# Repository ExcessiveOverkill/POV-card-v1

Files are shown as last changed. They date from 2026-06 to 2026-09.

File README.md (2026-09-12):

# Persistence of Vision Badge
Turn on then shake side to side to view the images or animations programmed into the badge.

## Specs:
- Requires 2x CR2032 batteries (badge is not rechargeable)
- Credit card sized: 2.1" x 3.3" (54mm x 84mm)
- 0.8mm PCB thickness, 4mm total thickness with components
- Black PCB soldermask
- 32 bright white leds
- ENIG (thin gold) plated

## Features:
- Image or animation display
- User programmable images/animations over USB-C
- User configurable modes set by tapping the badge
- 4-bit grayscale image support
- Many new display modes
- XYZ Accelerometer
- True power-off (batteries last when not in use)
- Auto power-off

# How to use:
## Turning On:
1. Press "ON" button on badge.
2. Badge will display power-on animation when first powered on.

Pressing the "ON" button once badge is already on will have no effect.

## Turning Off:
1. Do nothing
2. Badge will automatically power off after it is no longer being interacted with for around 20 seconds. It will also power off regardless of interaction after 5 minutes.

## Changing Mode:
1. Turn badge on
2. Tap top of badge downward 3 times quickly to enter the mode menue, it should display the current mode by turning on an LED. The distance the LED is from the bottom of the badge shows what mode it is in.
3. Tap top of badge downward to move LED down, Tap bottom of badge upward to move LED up
4. Wait 3 seconds for badge to enter new mode. You may shake the badge while in the mode menu to view what mode is selected.
5. Done!

## USB Programming:
1. Turn badge on
2. Plug into computer using a USB-C cable, ensure the cable can carry data and not only power.
3. Badge will display slow pulsing to indicate USB connection.
4. Badge should show up as a USB storage device (flash drive).
5. Copy your BMP file to the badge
6. Done!
   
### BMP File Requirements:
- 1-bit or 4-bit grayscale
- 8, 16, or 32 pixels tall
- 128 or less pixels wide (per frame)
- Filename must end in "1" or "2" to indicate which slot you want to program
- For animations (multiple frames displayed in sequence), the filename must start with "SEQ"
- Animation frames must be separated by a 1 pixel wide column of alternating colors (0-1 for 1-bit, 0-15 for 4-bit). With the top pixel starting as 1 or 15 (white).
- File size must be less than 2KB

## How to get a good image
Image quality greatly depends on the shaking motion. Use mode 8: "IMAGE LINE TEST" to visualize your shake motion.
### Things to improve display quality
- Hold badge further away
- Smooth, uniform shaking. Slower and more consistent is better than fast and crazy.
- Shake left/right, not tilted or up/down
- Symmetrical movement, *not* like trying to shake ketchup out of a bottle.

## Modes
### 1. DISPLAY BOTH
Display both the pre-programmed image/animation shipped with the badge as well as all custom user-programmed images/animations.

### 2. DISPLAY CUSTOM
Display only the custom user-programmed images/animations.

### 3. LEVEL
Emulates a bubble level. Hold the badge edge against a vertical or horizontal surface. Use the "LEVEL CAL" mode to improve accuracy.

### 4. BALL SIM
LEDs display a "ball" that reacts to how you move and tilt the badge.

### 5. SAVE MODE
Save the last selected mode and automatically switch to it on the next power-on.
This function requires verification (see below).

### 6. LEVEL CAL
Calibrate the angles the badge uses for "LEVEL" mode. After entering this mode, hold the long badge still against a known horizontal surface until the LEDs all turn on. Then hold the short edge still against the surface until the "bubble" resets to center.
This function requires verification (see below).

### 7. RESET
Clears all user-programmed memory. Badge will power off after this mode is selected.
This function requires verification (see below).

### 8. IMAGE LINE TEST
Displays a diagonal line. Useful for practicing the correct shake technique to get the best display results.
The line should be perfectly straight and vertical when you shake the badge. Slight distortion is acceptable, but if it is very distorted, read the "How to get a good image" section.

## Firmware Update (DANGER)
### 9. USB Device Firmware Update
Allows the badge to be fully reprogrammed with a new binary file using STM32CubeProgrammer over the USB port. `-ob nBOOT0=1` must be added when using the programmer to reset the DFU bit, otherwise the badge will be stuck in DFU mode. Once this mode is entered, the badge will not function until reprogrammed! "ON" button must be held down to program the badge in this mode *or* with an ST-LINK.
User-memory will also be cleared.

## Mode Verification
Certain modes are protected by a verification step to prevent accidental triggering.
These modes will display a bar at the bottom the image that slowly shrinks while you shake the badge.
You must continuously shake the badge until the bar is gone to enable the selected mode.

# Warnings/Notices:
- The badge is a bare PCB, it is very susceptible water and metallic objects and dust. Keep clean and do not put in contact with loose conductive objects
- Badge is not rechargeable, the USB-C port does not supply power to the badge circuitry.
- This "Development Edition" is the first publicly available version. There may be unforeseen issues with hardware or software that affect functionality. However we will do our best to verify all use cases and resolve potential issues before you receive your badge.
- Persistence-of-vision effects are notoriously hard to film. Cameras will not capture the effect well without a very slow shutter speed.
- Attached lanyards or clips that rattle against the badge will affect the accelerometer reading and can make the image distorted.

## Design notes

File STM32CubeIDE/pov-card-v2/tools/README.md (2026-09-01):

# POV-card-v2 asset tools

Offline code generators that bake image/font data into the firmware. They are **not**
part of the build — run them by hand when the assets change, then rebuild in STM32CubeIDE.

## Prerequisites

```
pip install pillow
```

## bmp_convert.py — built-in POV images

Converts up to **2** BMP files into `../Core/Inc/eo_image_data.h`
(`const uint8_t eo_image_data[]` + `const Image_Metadata eo_metadata[2]`), which `main.c`
pulls in with `#include "eo_image_data.h"` and places in the `.eo_image_data` flash region.

1. Put the BMP next to this script (or give a path relative to it).
2. Edit `INPUT_FILES` at the top of `bmp_convert.py` (1 or 2 entries).
3. `python bmp_convert.py`
4. Rebuild the `Debug` configuration in STM32CubeIDE and flash.

BMP constraints (enforced by the script):

| Property | Allowed |
|---|---|
| Bit depth | 1-bit **or** 4-bit, uncompressed |
| Height | 8, 16, or 32 px |
| Width | any (≤ 128 recommended); columns become POV lines |
| Frames | filename contains `sequence` → auto-split on alternating separator columns; else 1 frame; ≤ 128 |

Per-image timing is set by the `*_DISPLAY_CYCLES` / `*_CYCLE_COUNT` constants at the top
of the script (`SINGLE_*` for normal images, `SEQUENCE_*` for `sequence` animations).

`eo_metadata` is always exactly 2 entries; a missing second image is emitted as a zeroed
(`mode = ONE_BIT`, `frame_count = 0`) placeholder.

## letter_convert.py — A–Z label font

Converts `7x5_letters.png` (a 7-px-tall A–Z strip) into `font_data.txt`, a
`const uint8_t letter_pixels[]` table. That array is currently **pasted by hand** into
`../Core/Src/main.c` (search for `letter_pixels[]`). Bit layout: bits 6–0 = column pixels
(bit 0 = bottom row); bit 7 = last column of the glyph.

```
python letter_convert.py
```

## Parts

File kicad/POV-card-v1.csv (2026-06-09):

Reference | Value | Footprint | Qty | Manufacturer | LCSC# | Manufacturer part number
BT1,BT2 | Battery_Cell | footprints:cr2032 | 2 | MYOUNG | C19184123 | MY-2032-30-R
C1,C2,C3 | 4.7uf | Capacitor_SMD:C_0402_1005Metric | 3 | Samsung Electro-Mechanics | C23733 | CL05A475MP5NRNC
C4,C5,C6,C7,C8,C9,C10,C11 | .1uf | Capacitor_SMD:C_0402_1005Metric | 8 | Samsung Electro-Mechanics | C1525 | CL05B104KO5NNNC
D1,D2,D3,D4,D5,D6,D7,D8,D9,D10,D11,D12,D13,D14,D15,D16,D17,D18,D19,D20,D21,D22,D23,D24,D25,D26,D27,D28,D29,D30,D31,D32 | LED | LED_SMD:LED_0603_1608Metric | 32 | Hubei KENTO Elec | C2290 | KT-0603W
J2 | USB_C_Receptacle_USB2.0_16P | Connector_USB:USB_C_Receptacle_G-Switch_GT-USB-7010ASV | 1 | G-Switch | C2988369 | GT-USB-7010ASV
Q1 | Q_PMOS_GSD | Package_TO_SOT_SMD:SOT-23 | 1 | r Alpha & Omega Semicon | C15127 | AO3401A
Q2 | Q_NMOS_GSD | Package_TO_SOT_SMD:SOT-23 | 1 | Jiangsu Changjing Electronics Technology Co., Ltd. | C8545 | 2N7002
R1,R2,R4,R5 | 10k | Resistor_SMD:R_0402_1005Metric | 4 | UNI-ROYAL | C25744 | 0402WGF1002TCE
R3 | 1k | Resistor_SMD:R_0402_1005Metric | 1 | UNI-ROYAL | C11702 | 0402WGF1001TCE
SW1 | SW_Push | Button_Switch_SMD:SW_Push_1P1T_XKB_TS-1187A | 1 | XKB Connection | C318884 | TS-1187A-B-A-B
U1 | SC7A20 | Package_LGA:LGA-12_2x2mm_P0.5mm | 1 | Hangzhou Silan Microelectronics | C19274408 | SC7A20HTR
U2,U4 | USBLC6-2SC6 | Package_TO_SOT_SMD:SOT-23-6 | 2 | UMW(Youtai Semiconductor Co., Ltd.) | C2687116 | USBLC6-2SC6
U3,U5 | TLC59283RGER | footprints:RGE24_2P1X2P1_TEX | 2 | Texas Instruments | C485815 | TLC59283RGER
U6 | STM32C071G8Ux | Package_DFN_QFN:QFN-28_4x4mm_P0.5mm | 1 | STMicroelectronics | C44521811 | STM32C071G8U6
U7 | HT75xx-1-SOT89 | Package_TO_SOT_SMD:SOT-89-3 | 1 | Holtek Semicon | t # C14289 | HT7533-1

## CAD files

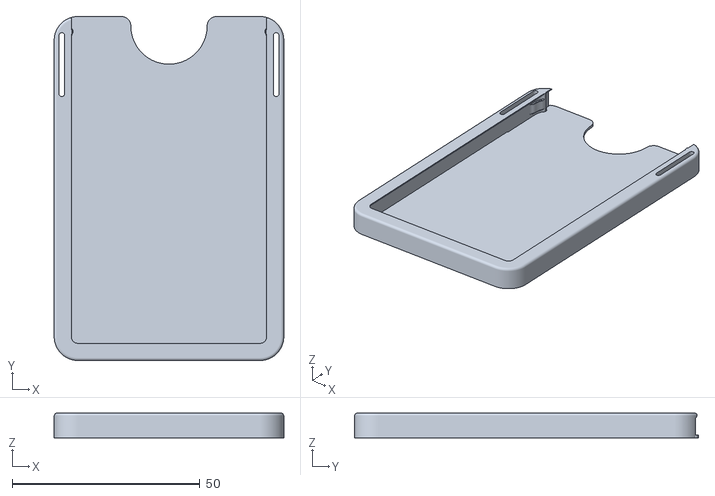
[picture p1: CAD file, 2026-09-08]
POV Badge Holder v3.stl
61.2 x 91.7 x 6.60

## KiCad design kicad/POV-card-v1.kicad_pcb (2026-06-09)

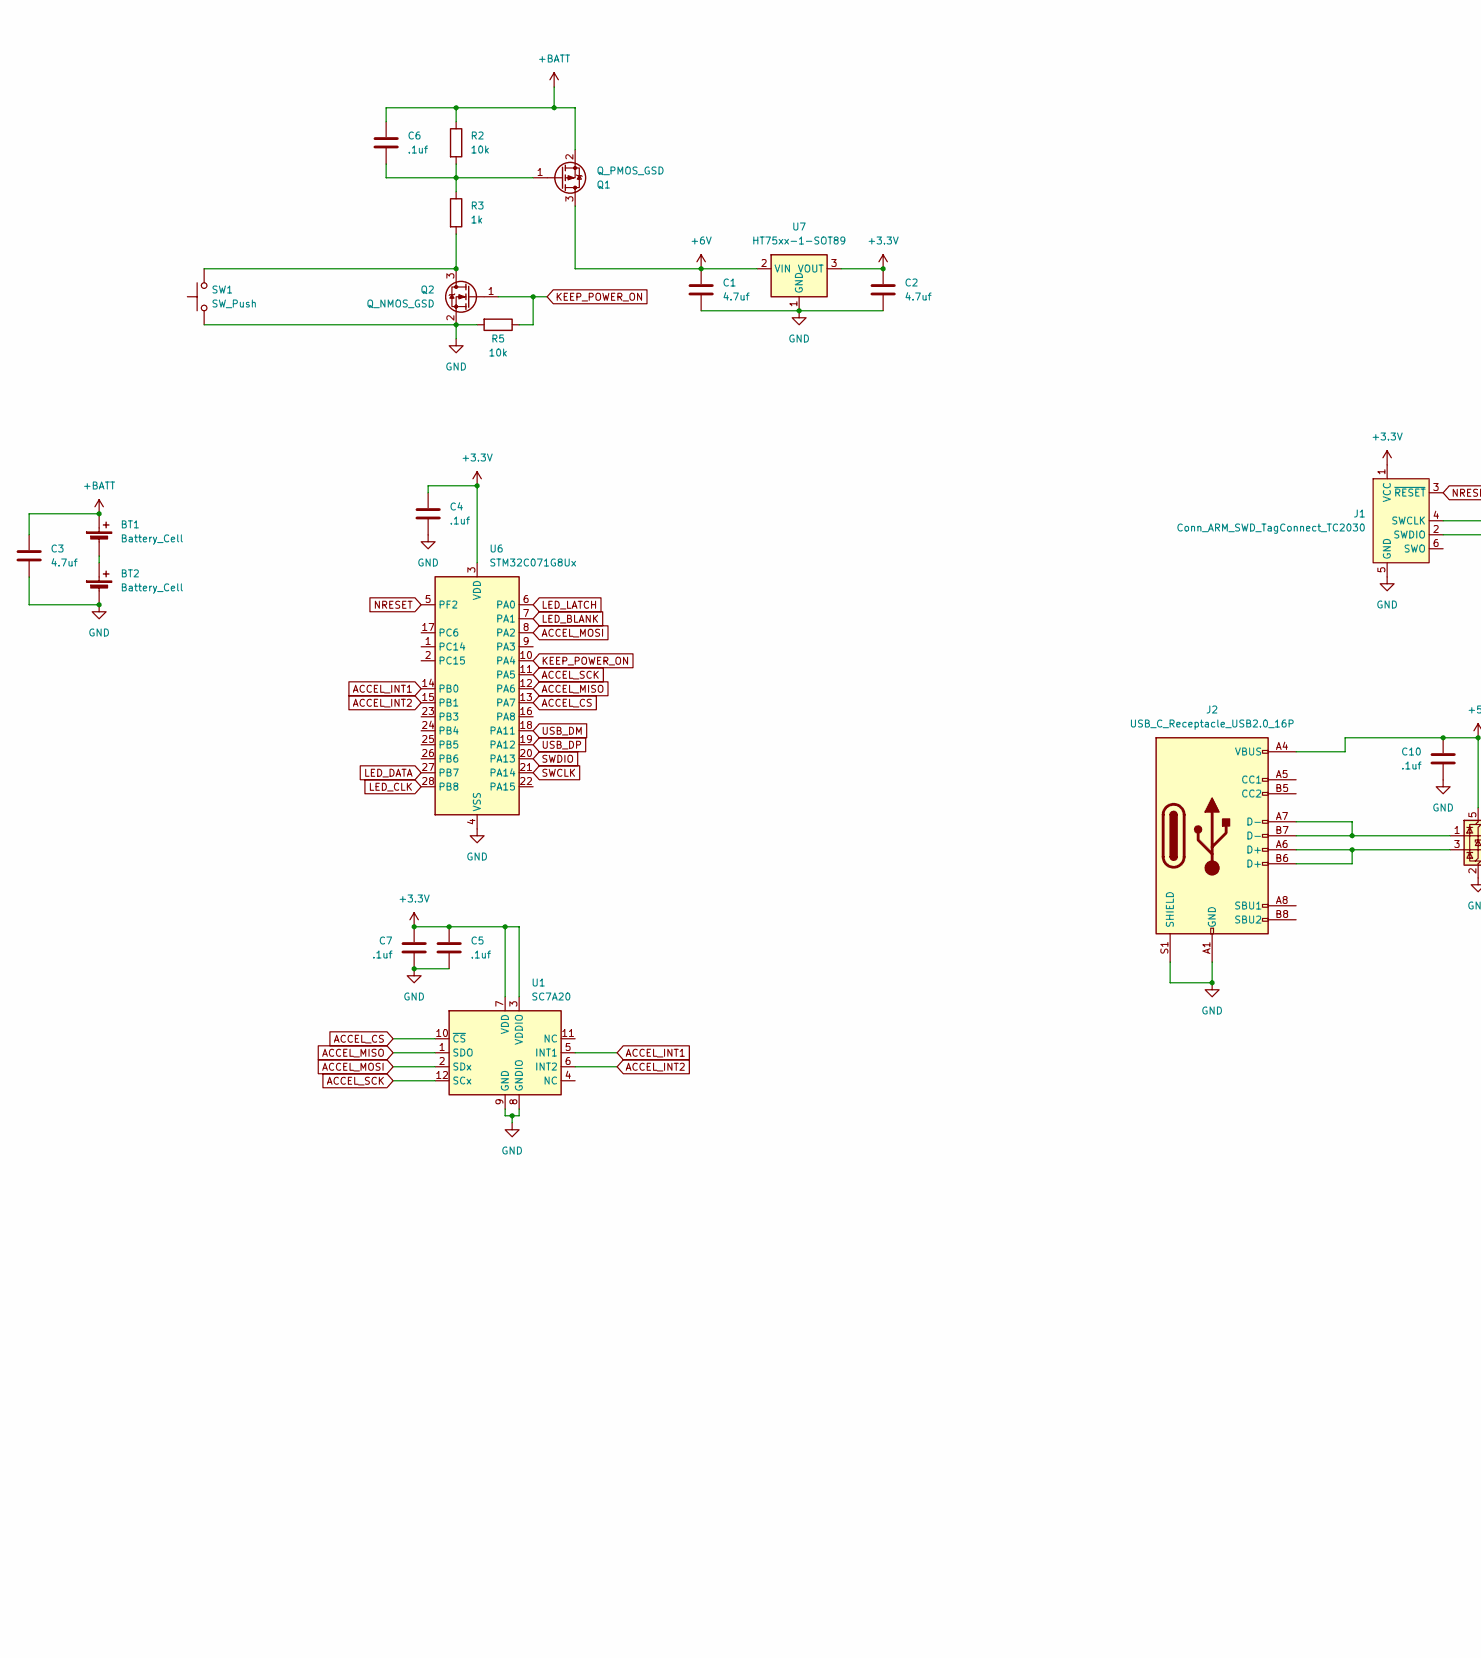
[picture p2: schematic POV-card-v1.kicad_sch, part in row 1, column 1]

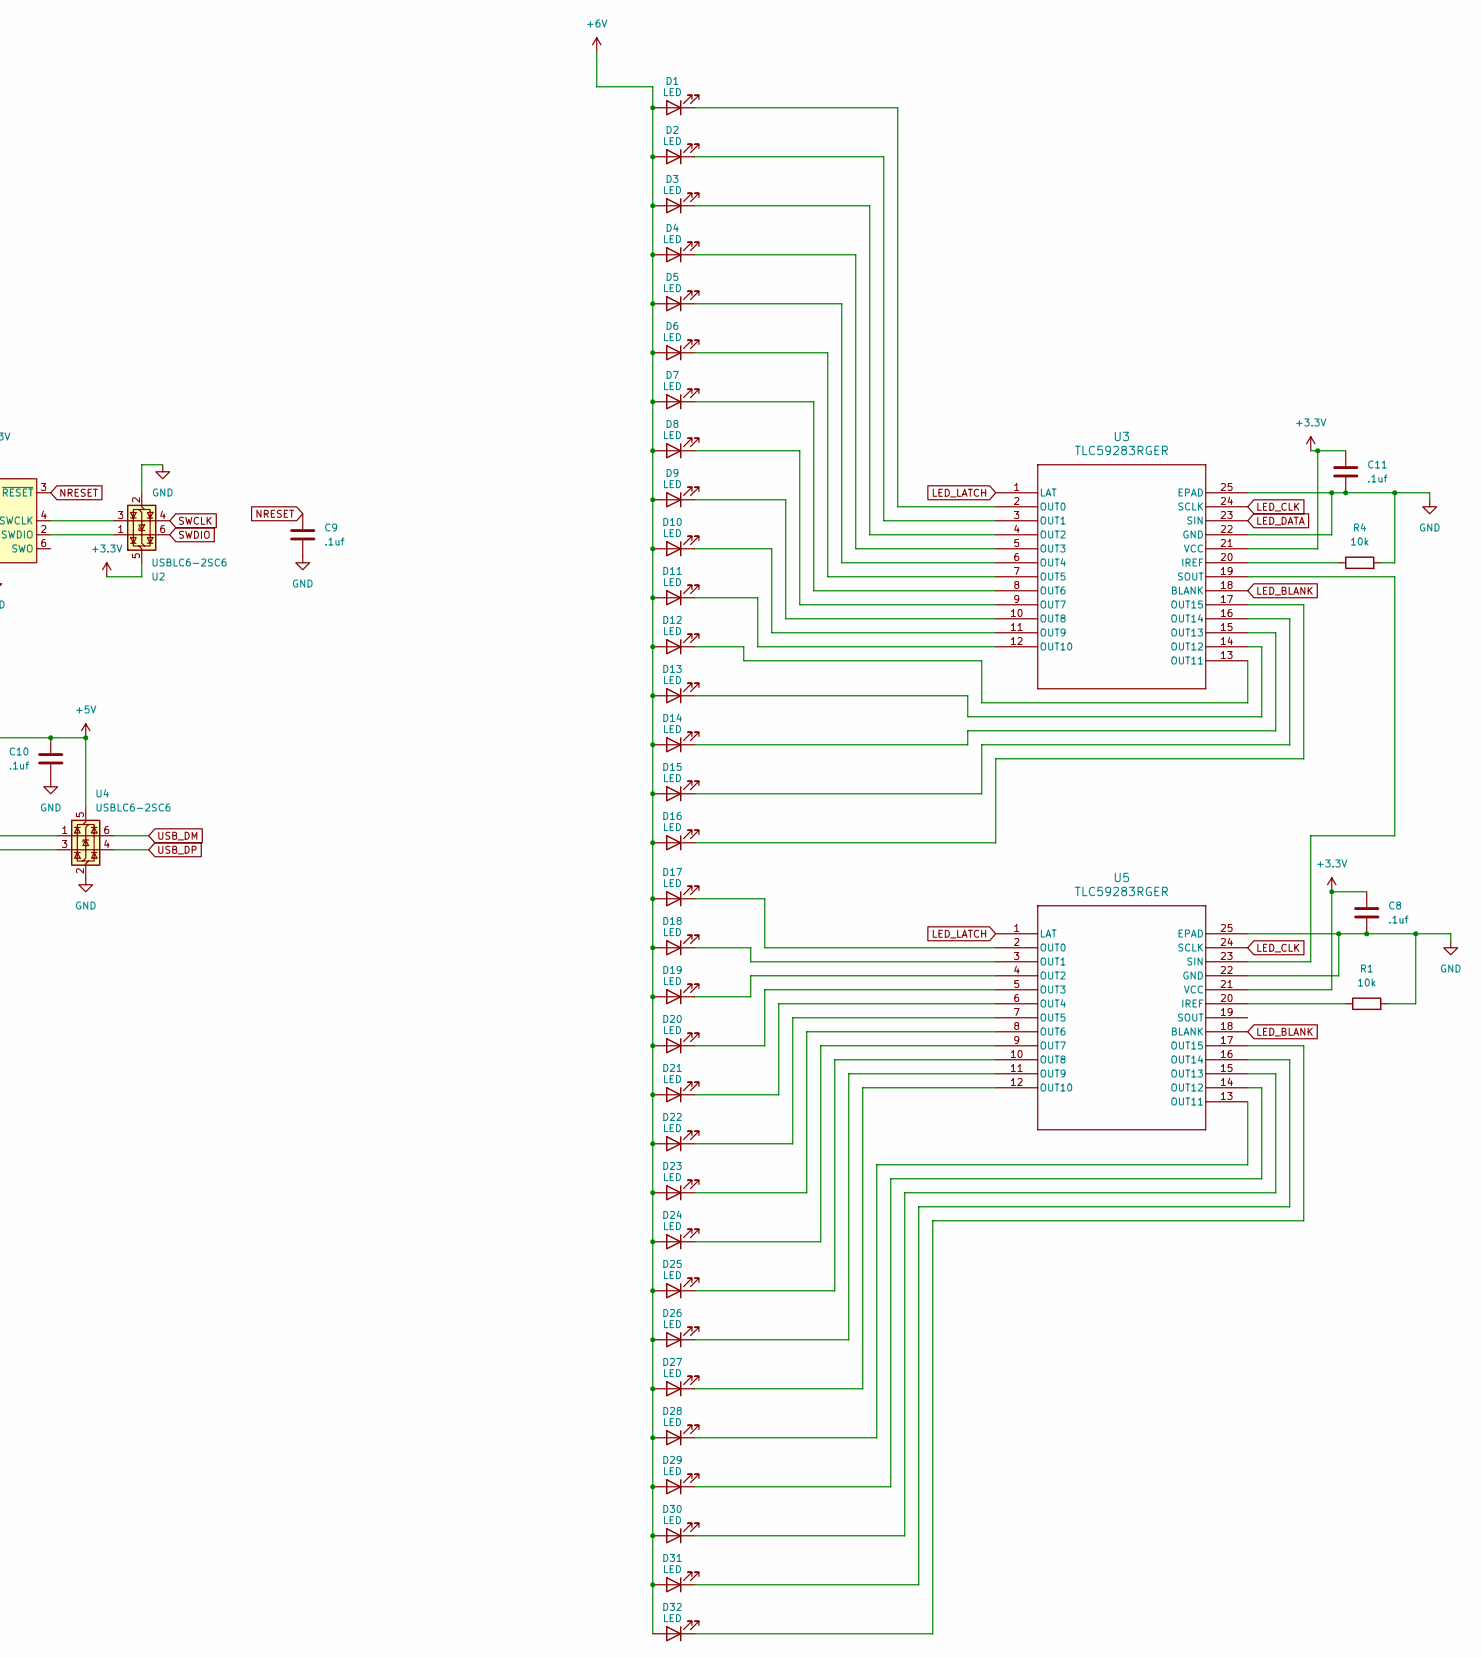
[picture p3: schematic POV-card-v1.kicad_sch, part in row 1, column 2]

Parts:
BT1, BT2: Battery_Cell; cr2032; Manufacturer part number MY-2032-30-R; LCSC# C19184123
C1, C2, C3: 4.7uf; C_0402_1005Metric; Manufacturer part number CL05A475MP5NRNC; LCSC# C23733
C4, C5, C6, C7, C8, C9, C10, C11: .1uf; C_0402_1005Metric; Manufacturer part number CL05B104KO5NNNC; LCSC# C1525
D1, D2, D3, D4, D5, D6, D7, D8, D9, D10, D11, D12, D13, D14, D15, D16, D17, D18, D19, D20, D21, D22, D23, D24, D25, D26, D27, D28, D29, D30, D31, D32: LED; LED_0603_1608Metric; Manufacturer part number KT-0603W; LCSC# C2290
J1: Conn_ARM_SWD_TagConnect_TC2030; Tag-Connect_TC2030-IDC-FP_2x03_P1.27mm_Vertical
J2: USB_C_Receptacle_USB2.0_16P; USB_C_Receptacle_G-Switch_GT-USB-7010ASV; Manufacturer part number GT-USB-7010ASV; LCSC# C2988369
Q1: Q_PMOS_GSD; SOT-23; Manufacturer part number AO3401A; LCSC# C15127
Q2: Q_NMOS_GSD; SOT-23; Manufacturer part number 2N7002; LCSC# C8545
R1, R2, R4, R5: 10k; R_0402_1005Metric; Manufacturer part number 0402WGF1002TCE; LCSC# C25744
R3: 1k; R_0402_1005Metric; Manufacturer part number 0402WGF1001TCE; LCSC# C11702
SW1: SW_Push; SW_Push_1P1T_XKB_TS-1187A; Manufacturer part number TS-1187A-B-A-B; LCSC# C318884
U1: SC7A20; LGA-12_2x2mm_P0.5mm; Manufacturer part number SC7A20HTR; LCSC# C19274408
U2, U4: USBLC6-2SC6; SOT-23-6; Manufacturer part number USBLC6-2SC6; LCSC# C2687116
U3, U5: TLC59283RGER; RGE24_2P1X2P1_TEX; Manufacturer part number TLC59283RGER; LCSC# C485815
U6: STM32C071G8Ux; QFN-28_4x4mm_P0.5mm; Manufacturer part number STM32C071G8U6; LCSC# C44521811
U7: HT75xx-1-SOT89; SOT-89-3; Manufacturer part number HT7533-1; LCSC# t # C14289

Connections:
+3.3V: C2.1, C4.1, C5.1, C7.1, C8.1, C11.1, J1.1 (VCC), U1.3 (VDDIO), U1.7 (VDD), U2.5 (VBUS), U3.21 (VCC), U5.21 (VCC), U6.3 (VDD), U7.3 (VOUT)
+5V: C10.1, J2.A4 (VBUS), J2.A9 (VBUS), J2.B4 (VBUS), J2.B9 (VBUS), U4.5 (VBUS)
+6V: C1.1, D1.2 (A), D2.2 (A), D3.2 (A), D4.2 (A), D5.2 (A), D6.2 (A), D7.2 (A), D8.2 (A), D9.2 (A), D10.2 (A), D11.2 (A), D12.2 (A), D13.2 (A), D14.2 (A), D15.2 (A), D16.2 (A), D17.2 (A), D18.2 (A), D19.2 (A), D20.2 (A), D21.2 (A), D22.2 (A), D23.2 (A), D24.2 (A), D25.2 (A), D26.2 (A), D27.2 (A), D28.2 (A), D29.2 (A), D30.2 (A), D31.2 (A), D32.2 (A), Q1.3 (D), U7.2 (VIN)
+BATT: BT1.1 (+), C3.1, C6.1, Q1.2 (S), R2.1
ACCEL_CS: U1.10 (~CS), U6.13 (PA7)
ACCEL_INT1: U1.5 (INT1), U6.14 (PB0)
ACCEL_INT2: U1.6 (INT2), U6.15 (PB1)
ACCEL_MISO: U1.1 (SDO), U6.12 (PA6)
ACCEL_MOSI: U1.2 (SDx), U6.8 (PA2)
ACCEL_SCK: U1.12 (SCx), U6.11 (PA5)
GND: BT2.2 (-), C1.2, C2.2, C3.2, C4.2, C5.2, C7.2, C8.2, C9.2, C10.2, C11.2, J1.5 (GND), J2.A1 (GND), J2.A12 (GND), J2.B1 (GND), J2.B12 (GND), J2.S1 (SHIELD), Q2.2 (S), R1.2, R4.2, R5.2, SW1.1, U1.8 (GNDIO), U1.9 (GND), U2.2 (GND), U3.22 (GND), U3.25 (EPAD), U4.2 (GND), U5.22 (GND), U5.25 (EPAD), U6.4 (VSS), U7.1 (GND)
KEEP_POWER_ON: Q2.1 (G), R5.1, U6.10 (PA4)
LED_BLANK: U3.18 (BLANK), U5.18 (BLANK), U6.7 (PA1)
LED_CLK: U3.24 (SCLK), U5.24 (SCLK), U6.28 (PB8)
LED_DATA: U3.23 (SIN), U6.27 (PB7)
LED_LATCH: U3.1 (LAT), U5.1 (LAT), U6.6 (PA0)
NRESET: C9.1, J1.3 (~RESET), U6.5 (PF2)
unnamed: BT1.2 (-), BT2.1 (+)
unnamed: D1.1 (K), U3.2 (OUT0)
unnamed: D2.1 (K), U3.3 (OUT1)
unnamed: D3.1 (K), U3.4 (OUT2)
unnamed: D4.1 (K), U3.5 (OUT3)
unnamed: D5.1 (K), U3.6 (OUT4)
unnamed: D6.1 (K), U3.7 (OUT5)
unnamed: D7.1 (K), U3.8 (OUT6)
unnamed: D8.1 (K), U3.9 (OUT7)
unnamed: D9.1 (K), U3.10 (OUT8)
unnamed: D10.1 (K), U3.11 (OUT9)
unnamed: D11.1 (K), U3.12 (OUT10)
unnamed: D12.1 (K), U3.13 (OUT11)
unnamed: D13.1 (K), U3.14 (OUT12)
unnamed: D14.1 (K), U3.15 (OUT13)
unnamed: D15.1 (K), U3.16 (OUT14)
unnamed: D16.1 (K), U3.17 (OUT15)
unnamed: D17.1 (K), U5.2 (OUT0)
unnamed: D18.1 (K), U5.3 (OUT1)
unnamed: D19.1 (K), U5.4 (OUT2)
unnamed: D20.1 (K), U5.5 (OUT3)
unnamed: D21.1 (K), U5.6 (OUT4)
unnamed: D22.1 (K), U5.7 (OUT5)
unnamed: D23.1 (K), U5.8 (OUT6)
unnamed: D24.1 (K), U5.9 (OUT7)
unnamed: D25.1 (K), U5.10 (OUT8)
unnamed: D26.1 (K), U5.11 (OUT9)
unnamed: D27.1 (K), U5.12 (OUT10)
unnamed: D28.1 (K), U5.13 (OUT11)
unnamed: D29.1 (K), U5.14 (OUT12)
unnamed: D30.1 (K), U5.15 (OUT13)
unnamed: D31.1 (K), U5.16 (OUT14)
unnamed: D32.1 (K), U5.17 (OUT15)
unnamed: J1.4 (SWCLK), U2.3 (I/O2)
unnamed: J1.2 (SWDIO), U2.1 (I/O1)
unnamed: J2.A6 (D+), J2.B6 (D+), U4.3 (I/O2)
unnamed: J2.A7 (D-), J2.B7 (D-), U4.1 (I/O1)
unnamed: C6.2, Q1.1 (G), R2.2, R3.1
unnamed: Q2.3 (D), R3.2, SW1.2
unnamed: R4.1, U3.20 (IREF)
unnamed: U3.19 (SOUT), U5.23 (SIN)
unnamed: R1.1, U5.20 (IREF)
SWCLK: U2.4 (I/O2), U6.21 (PA14)
SWDIO: U2.6 (I/O1), U6.20 (PA13)
USB_DM: U4.6 (I/O1), U6.18 (PA11)
USB_DP: U4.4 (I/O2), U6.19 (PA12)

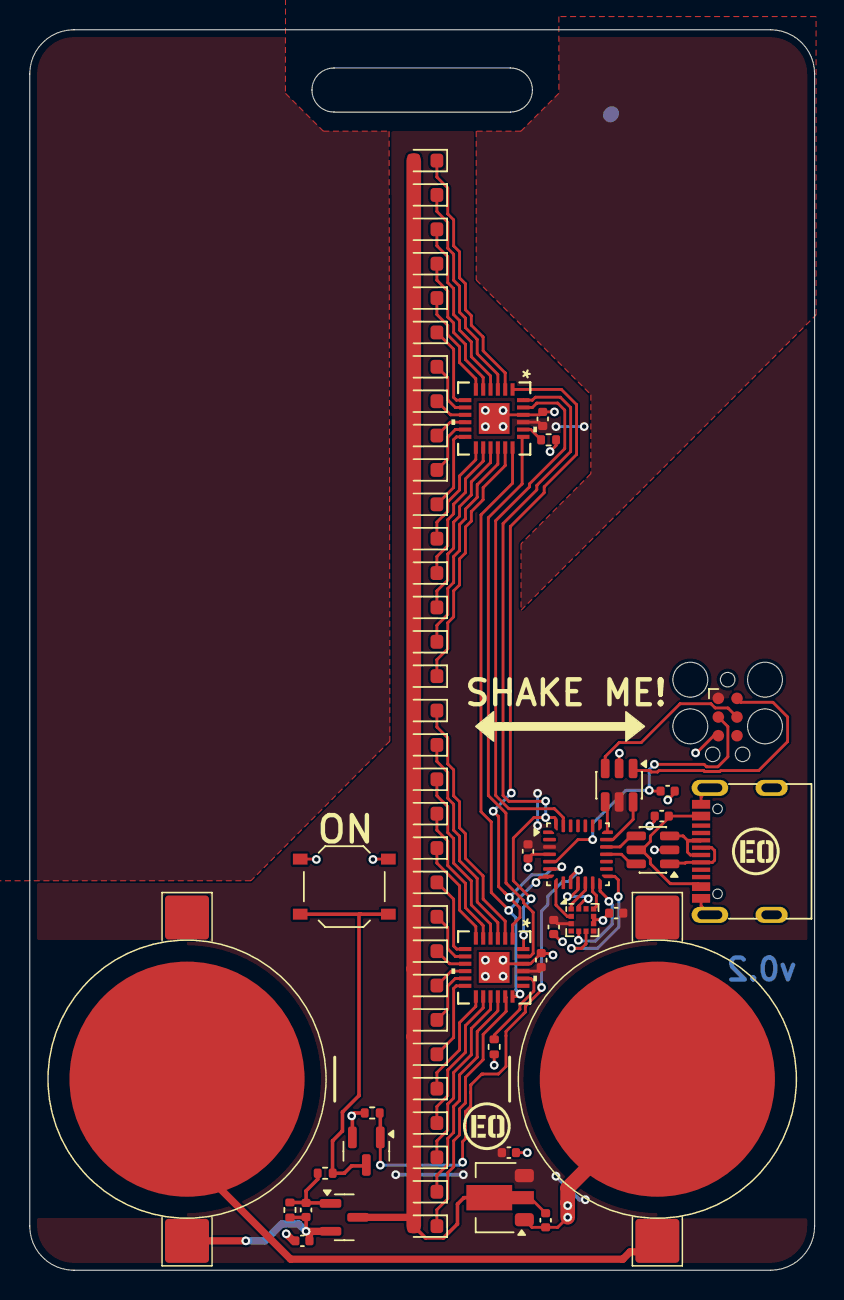
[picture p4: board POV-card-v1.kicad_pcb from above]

Board: 2 copper layers, 53.4 x 84.4 mm, 62 parts (0 on the bottom side), 63 nets.

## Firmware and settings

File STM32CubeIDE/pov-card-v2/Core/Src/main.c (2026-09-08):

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
/* Includes ------------------------------------------------------------------*/
#include "main.h"
#include "app_usbx_device.h"

/* USER CODE BEGIN Includes */
#include "math.h"
#include "ux_device_msc.h"
#include "pov_image.h"
#include "pov_bmp.h"
#include "pov_user_image.h"
#include <stdlib.h>
/* USER CODE END Includes */

/* USER CODE BEGIN PD */

#define MAX_POWER_OFF_DELAY 60*4	// how many seconds of being on before shutting off, regardless of activity
#define POWER_OFF_DELAY 20	// how many seconds of no movement before powering down
#define LED_ENABLE_ACCELERATION 6000

#define ACCEL_AVG_SHIFT 8

/* USER CODE END PD */


SPI_HandleTypeDef hspi1;
SPI_HandleTypeDef hspi2;
DMA_HandleTypeDef hdma_spi1_tx;
DMA_HandleTypeDef hdma_spi1_rx;
DMA_HandleTypeDef hdma_spi2_tx;

TIM_HandleTypeDef htim1;
TIM_HandleTypeDef htim2;
DMA_HandleTypeDef hdma_tim1_up;

PCD_HandleTypeDef hpcd_USB_DRD_FS;

/* USER CODE BEGIN PV */
static uint8_t s_img_buf[POV_USER_IMAGE_SLOT_BYTES];
static uint8_t s_usb_ready = 0U;
extern volatile uint8_t  g_usb_connected;
extern volatile uint8_t  g_bmp_pending;
extern volatile uint8_t  g_bmp_frame_idx;
extern volatile uint8_t  g_bmp_is_sequence;
extern volatile uint8_t  g_bmp_fill_level;
extern volatile uint8_t  g_usb_led_state;
extern volatile uint32_t g_bmp_ram_sector;
extern volatile uint32_t g_bmp_ram_size;

extern uint32_t _suser_image_data;
/* USER CODE END PV */

void SystemClock_Config(void);
static void MX_GPIO_Init(void);
static void MX_DMA_Init(void);
static void MX_USB_PCD_Init(void);
static void MX_SPI1_Init(void);
static void MX_SPI2_Init(void);
static void MX_TIM1_Init(void);
static void MX_DMAMUX_Init(void);
static void MX_TIM2_Init(void);
/* USER CODE BEGIN PFP */
extern UINT _ux_system_tasks_run(void);
/* USER CODE END PFP */

/* USER CODE BEGIN 0 */

const uint8_t letter_pixels[] = {
    0x3F, 0x48, 0x48, 0x48, 0xBF, 0x7F, 0x49, 0x49,
    0x49, 0xB6, 0x3E, 0x41, 0x41, 0x41, 0xC1, 0x7F,
    0x41, 0x41, 0x41, 0xBE, 0x7F, 0x49, 0x49, 0x41,
    0xC1, 0x7F, 0x48, 0x48, 0x40, 0xC0, 0x3E, 0x41,
    0x41, 0x49, 0xCE, 0x7F, 0x08, 0x08, 0x08, 0xFF,
    0x41, 0x7F, 0xC1, 0x02, 0x01, 0x41, 0x7E, 0xC0,
    0x7F, 0x08, 0x14, 0x22, 0xC1, 0x7F, 0x01, 0x01,
    0x01, 0x81, 0x7F, 0x20, 0x10, 0x20, 0xFF, 0x7F,
    0x30, 0x08, 0x06, 0xFF, 0x3E, 0x41, 0x41, 0x41,
    0xBE, 0x7F, 0x48, 0x48, 0x48, 0xB0, 0x3E, 0x41,
    0x45, 0x43, 0xBE, 0x7F, 0x48, 0x4C, 0x4A, 0xB1,
    0x32, 0x49, 0x49, 0x49, 0xA6, 0x40, 0x40, 0x7F,
    0x40, 0xC0, 0x7E, 0x01, 0x01, 0x01, 0xFE, 0x70,
    0x0E, 0x01, 0x0E, 0xF0, 0x7E, 0x01, 0x06, 0x01,
    0xFE, 0x63, 0x14, 0x08, 0x14, 0xE3, 0x60, 0x10,
    0x0F, 0x10, 0xE0, 0x43, 0x45, 0x49, 0x51, 0xE1,
    0x40, 0xFF, 0x21, 0x43, 0x45, 0x49, 0xB1, 0x22,
    0x41, 0x49, 0x49, 0xB6, 0x78, 0x08, 0x08, 0x08,
    0xFF, 0x7A, 0x49, 0x49, 0x49, 0xC6, 0x3E, 0x49,
    0x49, 0x49, 0xA6, 0x40, 0x40, 0x4F, 0x50, 0xE0,
    0x36, 0x49, 0x49, 0x49, 0xB6, 0x32, 0x49, 0x49,
    0x49, 0xBE, 0x3E, 0x43, 0x5D, 0x61, 0xBE,
};

// Total bytes: 175
// Letters found: 36
// Bit layout per byte: bits 6-0 = column pixels (bit 0 = bottom row)
// Bit 7 = 1 marks the last column of each letter

static uint32_t accel_last_update_time = 0;
static uint32_t accel_update_period = 1000;
static uint8_t new_accel_data = 0;

static const uint8_t accel_run_tx_request[1+2*3] = {(0b11 << 6) | 0x28, 0, 0, 0, 0, 0, 0};
static uint8_t accel_run_rx_data[1+2*3];

static int16_t accel_x_raw = 0;
static int16_t accel_y_raw = 0;
static int16_t accel_z_raw = 0;
static int32_t last_accel_x_raw = 0;
static int32_t last_accel_y_raw = 0;
static int32_t last_accel_z_raw = 0;

static uint32_t plane[16];

/* Image_Display_Mode / Image_Metadata / Nv_Metadata now live in pov_image.h */

__attribute__((section(".eo_image_data")))
#include "eo_image_data.h"


extern const Nv_Metadata _smeta_data;

static Nv_Metadata saved_metadata;

static uint16_t blank_ccr[16];
static uint16_t prev_blank_ccr[16];   // active curve saved while USB status is shown

static const uint16_t default_blank_ccr[16] = {
	128-1,
	128-1,
	128-1,
	128-2,
	128-2,
	128-4,
	128-5,
	128-10,
	128-20,
	128-30,
	128-40,
	128-50,
	128-60,
	128-80,
	128-127,
	128-127,
};

static const uint16_t ball_blank_ccr[16] = {
	128-1,
	128-1,
	128-1,
	128-2,
	128-2,
	128-4,
	128-5,
	128-6,
	128-6,
	128-6,
	128-6,
	128-6,
	128-6,
	128-6,
	128-6,
	128-6,
};

/* Curve used only while the USB host is connected (status pulse / fill bar /
   success / error). Smoother ramp than default so the low-brightness pulse is
   actually visible; tune the 16 values to taste. */
static const uint16_t usb_blank_ccr[16] = {
	128-1,
	128-1,
	128-1,
	128-1,
	128-1,
	128-2,
	128-2,
	128-2,
	128-4,
	128-4,
	128-4,
	128-4,
	128-4,
	128-4,
	128-4,
	128-4,
};

void EXTI0_1_IRQHandler(void)
{
    __HAL_GPIO_EXTI_CLEAR_IT(ACCEL_INT1_Pin);

    uint32_t tick = TIM2->CNT;
    accel_update_period = tick - accel_last_update_time;
    accel_last_update_time = tick;

    /* Assert CS */
    HAL_GPIO_WritePin(ACCEL_CS_GPIO_Port, ACCEL_CS_Pin, GPIO_PIN_RESET);

    /* Arm both DMA channels — RX first so it's ready before TX starts clocking */
    HAL_DMA_Start_IT(&hdma_spi1_rx,
                     (uint32_t)&hspi1.Instance->DR,
                     (uint32_t)accel_run_rx_data,
                     sizeof(accel_run_tx_request));
    HAL_DMA_Start(&hdma_spi1_tx,
                  (uint32_t)accel_run_tx_request,
                  (uint32_t)&hspi1.Instance->DR,
                  sizeof(accel_run_rx_data));

    /* Enable SPI DMA requests — TX firing first starts the clock */
    SET_BIT(hspi1.Instance->CR2, SPI_CR2_RXDMAEN);
    SET_BIT(hspi1.Instance->CR2, SPI_CR2_TXDMAEN);
}

static void Accel_DMA_RxComplete(DMA_HandleTypeDef *hdma)
{
	/* Deassert CS */
	HAL_GPIO_WritePin(ACCEL_CS_GPIO_Port, ACCEL_CS_Pin, GPIO_PIN_SET);

	/* Disable SPI DMA requests for next transaction */
	CLEAR_BIT(hspi1.Instance->CR2, SPI_CR2_RXDMAEN | SPI_CR2_TXDMAEN);

	/* Reset TX handle state — no TC interrupt on TX channel means HAL
	 * never clears STATE_BUSY automatically after the transfer completes */
	hdma_spi1_tx.State = HAL_DMA_STATE_READY;

	/* Clear SPI overrun flag — set when the last RX byte clocked in
	 * before DMA read it, leaving stale data in DR. If not cleared,
	 * SPI stops generating RX DMA requests on the next transaction. */
	__HAL_SPI_CLEAR_OVRFLAG(&hspi1);


	// save data
	last_accel_x_raw = accel_x_raw;
	last_accel_y_raw = accel_y_raw;
	last_accel_z_raw = accel_z_raw;
	accel_x_raw = accel_run_rx_data[1] | (accel_run_rx_data[2]<<8);
	accel_y_raw = accel_run_rx_data[3] | (accel_run_rx_data[4]<<8);
	accel_z_raw = accel_run_rx_data[5] | (accel_run_rx_data[6]<<8);
	new_accel_data = 1;

}

/* --------------------------------------------------------------------------
 * Start the LED system
 * Call after frame_buf is populated.
 * -------------------------------------------------------------------------- */
void LED_Start(void)
{
    HAL_DMA_Start(&hdma_spi2_tx,
                  (uint32_t)plane,
                  (uint32_t)&hspi2.Instance->DR,
                  sizeof(plane)/2);

    __HAL_SPI_ENABLE(&hspi2);

    HAL_DMA_Start(&hdma_tim1_up,
				  (uint32_t)blank_ccr,
				  (uint32_t)&TIM1->CCR2,
				  sizeof(blank_ccr)/2);



	__HAL_TIM_ENABLE_DMA(&htim1, TIM_DMA_UPDATE);

    HAL_TIM_PWM_Start(&htim1, TIM_CHANNEL_1);	// led latch
    HAL_TIM_PWM_Start(&htim1, TIM_CHANNEL_2);	// led blank
    HAL_TIM_PWM_Start(&htim1, TIM_CHANNEL_4);	// dma trigger

    HAL_TIM_Base_Stop(&htim1);
    TIM1->CNT = 0;

    SET_BIT(TIM1->DIER, TIM_DIER_UDE);
    SET_BIT(hspi2.Instance->CR2, SPI_CR2_TXDMAEN);

    HAL_TIM_Base_Start(&htim1);


}

/* Build from 4-bit brightness values. */
void BCM_BuildFrame(const uint8_t brightness[32])
{
	memset(plane, 0, sizeof(plane));	// zero

    for(int i = 0; i < 32; i++) {
        uint8_t b = brightness[i];

        for(int j = 0; j < b; j++){
        	plane[j] |= (1u << i);
        }
    }
}


uint8_t update_metadata(){

	FLASH_EraseInitTypeDef erase = {
		.TypeErase = FLASH_TYPEERASE_PAGES,
		.Page      = ((uint32_t)&_smeta_data - FLASH_BASE) / FLASH_PAGE_SIZE,
		.NbPages   = 1
	};

	uint32_t page_err = 0;

	HAL_FLASH_Unlock();
	HAL_StatusTypeDef status = HAL_FLASHEx_Erase(&erase, &page_err);
	HAL_FLASH_Lock();

	if(status != HAL_OK) return 1;

	uint8_t buf[sizeof(Nv_Metadata) + 8] = {0xFF};
	memcpy(buf, &saved_metadata, sizeof(Nv_Metadata));

	uint32_t base_addr = (uint32_t)&_smeta_data;

	HAL_FLASH_Unlock();

	for (uint32_t i = 0; i < sizeof(buf); i += 8)
	{
		uint64_t dword;
		memcpy(&dword, &buf[i], 8);

		status = HAL_FLASH_Program(FLASH_TYPEPROGRAM_DOUBLEWORD,
								   base_addr + i,
								   dword);
		if(status != HAL_OK) return 2;
	}

	HAL_FLASH_Lock();

	return 0;
}

void nvm_load_metadata(void) {
    memcpy(&saved_metadata, (const void *)&_smeta_data, sizeof(Nv_Metadata));
}


void enter_USB_bootloader(void)
{
	FLASH_OBProgramInitTypeDef ob = {0};

	HAL_FLASH_Unlock();
	HAL_FLASH_OB_Unlock();

	HAL_FLASHEx_OBGetConfig(&ob);

	ob.OptionType = OPTIONBYTE_USER;
	ob.USERType   = OB_USER_NBOOT_SEL | OB_USER_NBOOT0 | OB_USER_NBOOT1 | OB_USER_BOR_LEV; // BOOT_LOCK not in USERType on C0 HAL, cleared via FLASH_SECR below
	ob.USERConfig = (ob.USERConfig & ~(FLASH_OPTR_nBOOT_SEL | FLASH_OPTR_nBOOT0 |
										FLASH_OPTR_nBOOT1))
					| FLASH_OPTR_nBOOT_SEL | FLASH_OPTR_nBOOT1;   // nBOOT0=0, nBOOT_SEL=1, nBOOT1=1

	HAL_FLASHEx_OBProgram(&ob);

	CLEAR_BIT(FLASH->SECR, FLASH_SECR_BOOT_LOCK);   // BOOT_LOCK=0, separate register on C0

	HAL_FLASH_OB_Lock();
	HAL_FLASH_Lock();

	HAL_FLASH_OB_Launch();
}

#define NUM_LEDS   32
#define MAX_BRIGHT 15

void set_led_brightness(int32_t value, uint8_t leds[NUM_LEDS], const int32_t in_min, const int32_t in_max) {
    if (value < in_min) value = in_min;
    if (value > in_max) value = in_max;

    memset(leds, 0, NUM_LEDS);

    int32_t offset = value - in_min;      // 0 .. 4096
	int32_t range  = in_max - in_min;     // 4096

	int64_t pos_fp = ((int64_t)offset * (NUM_LEDS - 1) << 16) / range; // 16.16 fixed

	int32_t led_low = (int32_t)(pos_fp >> 16);
	int32_t frac    = (int32_t)(pos_fp & 0xFFFF);        // 0 .. 65535

	if (led_low >= NUM_LEDS - 1) {
		leds[NUM_LEDS - 1] = MAX_BRIGHT;
		return;
	}

	int32_t bright_high = (frac * MAX_BRIGHT + 32768) / 65536; // round, not truncate
	int32_t bright_low  = MAX_BRIGHT - bright_high;

	leds[led_low]     = (uint8_t)bright_low;
	leds[led_low + 1] = (uint8_t)bright_high;
}


/* USER CODE END 0 */

/**
  * @brief  The application entry point.
  * @retval int
  */
int main(void)
{

  /* MCU Configuration--------------------------------------------------------*/

  /* Reset of all peripherals, Initializes the Flash interface and the Systick. */
  HAL_Init();

  /* Configure the system clock */
  SystemClock_Config();

  /* Initialize all configured peripherals */
  MX_GPIO_Init();
  MX_DMA_Init();
  MX_USB_PCD_Init();
  MX_SPI1_Init();
  MX_SPI2_Init();
  MX_USBX_Device_Init();
  MX_TIM1_Init();
  MX_DMAMUX_Init();
  MX_TIM2_Init();
  /* USER CODE BEGIN 2 */

  HAL_TIM_Base_Start(&htim2);

  // lock on power
  HAL_GPIO_WritePin(KEEP_POWER_ON_GPIO_Port, KEEP_POWER_ON_Pin, GPIO_PIN_SET);

  uint32_t tick = 0;
  uint32_t last_active_tick = 0;

  int32_t low_cut_integrator_rate = 10; // max accel magnitude to reduce toward zero each cycle. this is used to remove affects of gravity
  int32_t x_low_cut_integrator = 0;

int32_t x_accel = 0;
int32_t x_accel_interpolated = 0;
int32_t x_accel_previous = 0;
int32_t max_dynamic_accel = 0x7FFF; // acceleration needed to reach ends of image, this should adjust based on the measured max acceleration


int32_t x_accel_magnitude_average = 0;

int32_t image_line = 0;

int32_t max_cycle_accel = 0;
int32_t min_cycle_accel = 0;
uint32_t max_cycle_accel_time = 0;
uint32_t min_cycle_accel_time = 0;

uint32_t estimated_next_edge_time = 0;	// when we think we will be at the end of the shake motion again
uint32_t frame_trigger_time = 0xFFFFFFFF;

int32_t frame_length = 0;

uint32_t current_frame_cycle = 0;
uint32_t frame_display_cycles = 0;

uint32_t current_frame = 0;

int32_t avg_x_accel = 0;
int32_t avg_y_accel = 0;
int32_t avg_z_accel = 0;

const int16_t tap_threshold = 8000;
const uint32_t debounce_time = 50e3;
static uint32_t last_tap_time = 0;
static int16_t tap_accel = 0;
static int8_t tap_direction = 0;
static int8_t consecutive_taps = 0;

static uint8_t save_mode_enable = 0;

static uint8_t level_cal_mode_enable = 0;
static uint8_t x_cal_done = 1;
static uint8_t y_cal_done = 1;

static uint8_t save_metadata = 0;


  memcpy(blank_ccr, default_blank_ccr, sizeof(blank_ccr));


  // Configure and start accelerometer
  HAL_DMA_RegisterCallback(&hdma_spi1_rx, HAL_DMA_XFER_CPLT_CB_ID, Accel_DMA_RxComplete);

  uint8_t spi_buf[2] = {0, 0};

  spi_buf[0] = 0x23;
//  spi_buf[1] = 0b10 << 4;	// 8G range
  spi_buf[1] = (0b1 << 3) | (0b10 << 4);	// 8G range, high res mode
  HAL_GPIO_WritePin(ACCEL_CS_GPIO_Port, ACCEL_CS_Pin, GPIO_PIN_RESET);
  HAL_SPI_Transmit(&hspi1, spi_buf, 2, 1);
  HAL_GPIO_WritePin(ACCEL_CS_GPIO_Port, ACCEL_CS_Pin, GPIO_PIN_SET);
  HAL_Delay(1);

  spi_buf[0] = 0x22;
  spi_buf[1] = 0b1 << 4;	// DRDY1 interrupt
  HAL_GPIO_WritePin(ACCEL_CS_GPIO_Port, ACCEL_CS_Pin, GPIO_PIN_RESET);
  HAL_SPI_Transmit(&hspi1, spi_buf, 2, 1);
  HAL_GPIO_WritePin(ACCEL_CS_GPIO_Port, ACCEL_CS_Pin, GPIO_PIN_SET);
  HAL_Delay(1);

  spi_buf[0] = 0x20;
  spi_buf[1] = 0b111 | (0b1001 << 4);	// xyz enable and ODR set to max
//  spi_buf[1] = 0b111 | (0b0110 << 4);	// xyz enable and ODR set to 200Hz
  HAL_GPIO_WritePin(ACCEL_CS_GPIO_Port, ACCEL_CS_Pin, GPIO_PIN_RESET);
  HAL_SPI_Transmit(&hspi1, spi_buf, 2, 1);
  HAL_GPIO_WritePin(ACCEL_CS_GPIO_Port, ACCEL_CS_Pin, GPIO_PIN_SET);

  // enable NVIC edge trigger for accel data ready signal
  HAL_NVIC_SetPriority(EXTI0_1_IRQn, 1, 0);
  HAL_NVIC_EnableIRQ(EXTI0_1_IRQn);
  // enable NVIC dma for accel data
  HAL_NVIC_SetPriority(DMAMUX1_DMA1_CH4_5_IRQn, 1, 0);
  HAL_NVIC_EnableIRQ(DMAMUX1_DMA1_CH4_5_IRQn);

  EXTI0_1_IRQHandler();	// trigger a read


  enum Led_Mode{
    OFF,
	START_UP,
	MODE_SELECT,
    USB_READY,
    PROGRAMMING,
    SUCCESS,
    ERROR_BMP,
	ERROR_USB,
	FLASH_ERROR,
    POV_DISPLAY_BOTH,
	POV_DISPLAY_USER,
	ACCEL_X_RAW_DISPLAY,
	ACCEL_Y_RAW_DISPLAY,
	ACCEL_Z_RAW_DISPLAY,
	LED_DYNAMIC_DIM_DISPLAY,
	LED_DYNAMIC_DISPLAY,
	LED_ALL_ON,
	LEVEL,
	BALL_SIM,
	SAVE_MODE,
	LEVEL_CAL,
	RESET,
	USB_DFU,
	IMAGE_LINE_DISPLAY,
	POWER_OFF,
	INITIAL_SETUP_CAL,
	END
  } led_mode = START_UP;

  enum Mode{
	  MODE_POV_DISPLAY_BOTH,
	  MODE_POV_DISPLAY_USER_ONLY,
	  MODE_LEVEL,
	  MODE_BALL_SIM,
	  MODE_SAVE_MODE,
	  MODE_LEVEL_CAL,
	  MODE_RESET,
	  MODE_USB_DFU,
	  MODE_END,
	  MODE_IMAGE_LINE_DISPLAY,
	  MODE_ACCEL_X_RAW_DISPLAY,
	  MODE_ACCEL_Y_RAW_DISPLAY,
	  MODE_ACCEL_Z_RAW_DISPLAY,
	  MODE_LED_DYNAMIC_DIM_DISPLAY,
	  MODE_LED_DYNAMIC_DISPLAY

  }	mode = 0;

  nvm_load_metadata();

  // reset nvm metadata if it is not initialized
  if(saved_metadata.user_images[0].mode == 255 || saved_metadata.user_images[1].mode == 255){
	  led_mode = RESET;
  }

  // run setup and calibration on first program
  if(saved_metadata.first_run != 0){
	  led_mode = INITIAL_SETUP_CAL;
  }


  /* Guard: only call _ux_system_tasks_run if USBX fully initialised.
     MX_USBX_Device_Init() runs before this USER CODE section; if the
     memory pool was too small the DCD function pointer stays NULL and
     calling tasks_run causes a hard fault. */
  s_usb_ready = (_ux_system_slave != UX_NULL &&
                 _ux_system_slave->ux_system_slave_dcd.ux_slave_dcd_function != UX_NULL)
                ? 1U : 0U;


  if (!s_usb_ready) {
      led_mode = ERROR_USB;
  }


  uint8_t brightness[32];
  memset(brightness, 0, 32);

  uint32_t next_increment_tick = 0;

  BCM_BuildFrame(brightness);

  // start led DMA update
  LED_Start();

  enum Led_Mode default_led_mode = MODE_SELECT;
  enum Led_Mode prev_led_mode = MODE_SELECT;   // mode to restore when USB unplugs
  enum Mode last_mode = MODE_POV_DISPLAY_BOTH;

  // use saved mode for default
  if(saved_metadata.startup_mode < MODE_END){
	  mode = saved_metadata.startup_mode;
  }

  /* USER CODE END 2 */

  /* Infinite loop */
  /* USER CODE BEGIN WHILE */
  while (1)
  {
	tick = TIM2->CNT;	// ticks are in microseconds
	tap_direction = 0;

	if(new_accel_data){
		new_accel_data = 0;

		if(x_accel_magnitude_average > LED_ENABLE_ACCELERATION){
			if(x_accel_previous < 0 && x_accel >= 0){	// transitioned from negative to positive acceleration
				max_cycle_accel = 0;	// clear previous max recorded accel
				estimated_next_edge_time = (min_cycle_accel_time-max_cycle_accel_time) + min_cycle_accel_time;
			}

			if(x_accel_previous > 0 && x_accel <= 0){	// transitioned from positive to negative acceleration
				min_cycle_accel = 0;	// clear previous min recorded accel
				estimated_next_edge_time = (max_cycle_accel_time-min_cycle_accel_time) + max_cycle_accel_time;
			}
		}

		if(estimated_next_edge_time > tick + 500000) estimated_next_edge_time = tick;	// limit to sensible range

		x_accel_previous = x_accel;

		// integrate towards zero to cancel constant acceleration (gravity)
		x_accel = accel_x_raw + x_low_cut_integrator;

		// run integrator
		if(x_accel > low_cut_integrator_rate){
			x_low_cut_integrator -= low_cut_integrator_rate;
		}
		else if(x_accel < -low_cut_integrator_rate){
			x_low_cut_integrator += low_cut_integrator_rate;
		}
		else{
			x_low_cut_integrator -= x_accel;
		}

		// estimate average magnitude (used to detect motion)
		x_accel_magnitude_average += (abs(x_accel) - x_accel_magnitude_average) / 200;


		if(x_accel>max_cycle_accel){
			max_cycle_accel = x_accel;
			max_cycle_accel_time = tick;
		}

		if(x_accel<min_cycle_accel){
			min_cycle_accel = x_accel;
			min_cycle_accel_time = tick;
		}

		avg_x_accel += (int32_t)accel_x_raw - (avg_x_accel >> ACCEL_AVG_SHIFT);
		avg_y_accel += (int32_t)accel_y_raw - (avg_y_accel >> ACCEL_AVG_SHIFT);
		avg_z_accel += (int32_t)accel_z_raw - (avg_z_accel >> ACCEL_AVG_SHIFT);

		tap_accel = accel_y_raw - (avg_y_accel >> ACCEL_AVG_SHIFT);

		if(((abs(tap_accel) > tap_threshold) &&  (tick > (last_tap_time + debounce_time)))){

		    if(tap_accel > 0){
		    	tap_direction = 1;
		    }
		    else{
		    	tap_direction = -1;
		    }

		    if(led_mode != MODE_SELECT){
				if(consecutive_taps == 0){
					consecutive_taps = tap_direction;
				}
				else if(consecutive_taps < 0 && tap_direction < 0){
					consecutive_taps--;
				}
				else if(consecutive_taps > 0 && tap_direction > 0){
					consecutive_taps++;
				}
				else{
					consecutive_taps = 0;
				}
			}

		    last_tap_time = tick;
			last_active_tick = tick;
		}

		if(last_tap_time + 400e3 < tick){
			switch(consecutive_taps){
				case 3:
					led_mode = MODE_SELECT;
				break;
				default:
				break;
			}
			consecutive_taps = 0;
		}

	}

	// interpolate acceleration steps to get a smooth change
	x_accel_interpolated = x_accel_previous * (int32_t)accel_update_period + (x_accel / (int32_t)(tick-accel_last_update_time));
	x_accel_interpolated /= (int32_t)accel_update_period;

	// find line of image to display based on current acceleration and image length
	image_line =  ((x_accel_interpolated + max_dynamic_accel/2) / (max_dynamic_accel / frame_length));

	/* The LEDs show USB status instead of the normal mode while a host is
	   connected OR an upload is actively being processed (g_usb_led_state >= 2),
	   using their own blank_ccr brightness curve. On exit we restore the mode
	   and curve that were active before. ERROR_USB (USBX init failure) is a
	   separate permanent state and is not part of this.

	   `shown` is the status actually on screen; each PROGRAMMING/SUCCESS/ERROR
	   gets a minimum on-screen hold so quick uploads don't flash past. */
	{
		static const uint32_t PROG_HOLD = 500000U;	// >= 0.5 s "writing"
		static const uint32_t OK_HOLD   = 500000U;	// 0.5 s "done"
		static const uint32_t ERR_HOLD  = 3500000U;	// 3.5 s "error"

		static uint8_t  usb_status_active = 0;
		static uint8_t  shown = 0;			// 0/1 idle-ready, 2 prog, 3 ok, 4 err
		static uint32_t shown_until = 0;

		uint8_t want_status = (g_usb_connected || g_usb_led_state >= 2U);

		if(led_mode != POWER_OFF){	// if we run out of time, prevent usb from keeping card on and draining the battery
			if(!usb_status_active){
				if(want_status && led_mode != USB_DFU && led_mode != ERROR_USB){
					usb_status_active = 1;
					prev_led_mode = led_mode;
					memcpy(prev_blank_ccr, blank_ccr, sizeof(blank_ccr));
					memcpy(blank_ccr, usb_blank_ccr, sizeof(blank_ccr));
					shown = 0;
					shown_until = 0;
				}
			}
			else if(want_status || tick < shown_until){
				if(g_usb_connected) last_active_tick = tick;	// don't sleep while plugged in

				/* Adopt a new status only once the current one has had its hold. */
				if(g_usb_led_state != shown && tick >= shown_until){
					shown = g_usb_led_state;
					shown_until = tick + (shown == 2U ? PROG_HOLD :
										  shown == 3U ? OK_HOLD   :
										  shown == 4U ? ERR_HOLD  : 0U);
				}
				/* A finished SUCCESS/ERROR drops back to ready once its hold ends. */
				if(shown >= 3U && tick >= shown_until){
					shown = 1U;
					g_usb_led_state = 1U;
				}

				switch(shown){
					case 2:  led_mode = PROGRAMMING; break;
					case 3:  led_mode = SUCCESS;     break;
					case 4:  led_mode = ERROR_BMP;   break;
					default: led_mode = USB_READY;   break;	// 0 (idle) or 1 (ready)
				}
			}
			else{	// USB gone and no status hold pending -> restore
				usb_status_active = 0;
				shown = 0;
				shown_until = 0;
				led_mode = prev_led_mode;
				g_usb_led_state = 0;
				memcpy(blank_ccr, prev_blank_ccr, sizeof(blank_ccr));
			}
		}
	}

    switch (led_mode) {
      default:
      case OFF:
    	  memset(brightness, 0, 32);	// all off
    	  break;
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

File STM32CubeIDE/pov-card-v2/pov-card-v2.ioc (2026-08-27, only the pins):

Mcu.UserName=STM32C071G8Ux
PA0.GPIO_Label=LED_LATCH
PA0.Signal=S_TIM1_CH1
PA1.GPIO_Label=LED_BLANK
PA1.Signal=S_TIM1_CH2
PA13.Signal=DEBUG_SWDIO
PA14-BOOT0.Signal=DEBUG_SWCLK
PA2.GPIO_Label=ACCEL_MOSI
PA2.Signal=SPI1_MOSI
PA3.GPIO_Label=DMA_TRIG
PA3.Signal=SharedStack_PA3
PA4.GPIO_Label=KEEP_POWER_ON
PA4.Signal=GPIO_Output
PA5.GPIO_Label=ACCEL_SCK
PA5.Signal=SPI1_SCK
PA6.GPIO_Label=ACCEL_MISO
PA6.Signal=SPI1_MISO
PA7.GPIO_Label=ACCEL_CS
PA7.Signal=GPIO_Output
PB0.GPIO_Label=ACCEL_INT1
PB0.Signal=GPXTI0
PB1.GPIO_Label=ACCEL_INT2
PB1.Signal=GPIO_Input
PB6.Signal=GPIO_Output
PB7.GPIO_Label=LED_DATA
PB7.Signal=SPI2_MOSI
PB8.GPIO_Label=LED_CLK
PB8.Signal=SPI2_SCK

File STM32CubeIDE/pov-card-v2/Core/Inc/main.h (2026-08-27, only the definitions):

#define LED_LATCH_Pin GPIO_PIN_0
#define LED_LATCH_GPIO_Port GPIOA
#define LED_BLANK_Pin GPIO_PIN_1
#define LED_BLANK_GPIO_Port GPIOA
#define ACCEL_MOSI_Pin GPIO_PIN_2
#define ACCEL_MOSI_GPIO_Port GPIOA
#define DMA_TRIG_Pin GPIO_PIN_3
#define DMA_TRIG_GPIO_Port GPIOA
#define KEEP_POWER_ON_Pin GPIO_PIN_4
#define KEEP_POWER_ON_GPIO_Port GPIOA
#define ACCEL_SCK_Pin GPIO_PIN_5
#define ACCEL_SCK_GPIO_Port GPIOA
#define ACCEL_MISO_Pin GPIO_PIN_6
#define ACCEL_MISO_GPIO_Port GPIOA
#define ACCEL_CS_Pin GPIO_PIN_7
#define ACCEL_CS_GPIO_Port GPIOA
#define ACCEL_INT1_Pin GPIO_PIN_0
#define ACCEL_INT1_GPIO_Port GPIOB
#define ACCEL_INT2_Pin GPIO_PIN_1
#define ACCEL_INT2_GPIO_Port GPIOB
#define LED_DATA_Pin GPIO_PIN_7
#define LED_DATA_GPIO_Port GPIOB
#define LED_CLK_Pin GPIO_PIN_8
#define LED_CLK_GPIO_Port GPIOB

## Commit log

2026-08-27 add stm32 project
2026-09-01 add level calibration
2026-09-06 fix python seq converter
    [main.c]
2026-09-08 Update README with firmware update details and remove modes
    Removed several diagnostic modes and updated the USB Device Firmware Update section with additional details.
2026-09-08 fix mac USB programming, remove diag modes, fix level calibration
    [main.c]
2026-09-08 Update USB firmware update instructions in README
    Clarify the requirements for entering USB Device Firmware Update mode.
2026-09-08 Add STL of 3D-printable badge holder
    [POV Badge Holder v3.stl]
2026-09-08 only allow certain modes to save for next power-on

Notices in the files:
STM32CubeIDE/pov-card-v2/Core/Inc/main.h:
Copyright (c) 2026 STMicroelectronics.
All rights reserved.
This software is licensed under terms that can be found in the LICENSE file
